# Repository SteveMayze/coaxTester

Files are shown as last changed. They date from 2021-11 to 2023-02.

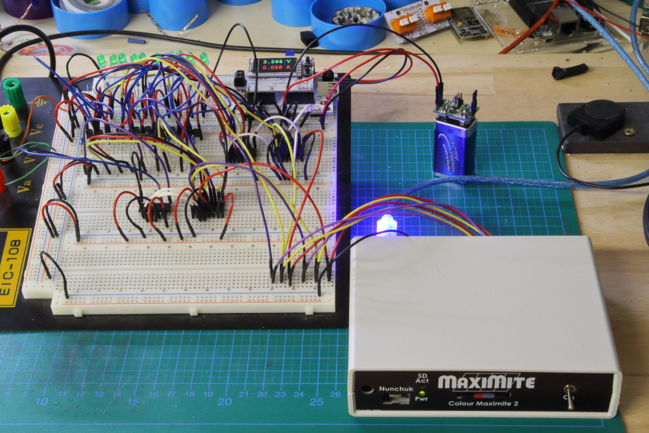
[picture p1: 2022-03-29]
doc/IMG_0029.JPG

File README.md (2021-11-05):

# Coaxial Cable Tester

05 Nov 2021

The purpose of this project is to create a simple device to test a series of coaxial cables where the ends are not situated near each other making it difficult to check continuity. For instance where one end of the cabe is terminated at the multi-switch and the other end at the satillite dish outside. The features of the device should be

1. Able to check continuity of the central conductor and the shielding
2. Able to detect shorts between the central conductor and the shiedling
3. Be able to identify the respective ends of the cable to assist with connection to the LNB and the multi-switch.

The device will be in two parts. A head tester and a tail tester. These devices will work together to determine the above conditions. The head testing will be the main unit and will contain a MCU and a radio unit - or a MCU enabled radio unit. There are a couple of options in this space. The second unit will contain only a MCU enabled radio unit.

# Operation
Each cable will be connected to the head unit and the tail unit respectively as best as it is known. 
```
     ---+
        |            
    L   +---- Low Horiz
    N   |
    B   +---- Low Vert
    1   |
        +--- High Horiz
        |
        +--- High Vert
        |
        +--- DVBT
        |
    L   +---- Low Horiz
    N   |
    B   +---- Low Vert
    2   |
        +--- High Horiz
        |
        +--- High Vert
        |
     ---+
```

The check is then intiated. The head-device will send a signal to the tail-device to open all contacts. Power is then applied to each channel in turn to test if there are any shorts.
The head-device will then send a signal to the tail-device to close all contacts. The head-device will then apply power to each channel again and check for continuity. It is at this stach that the order of the connection can also be verifed. i.e. if the output is sent out to Low Horiz but the return line for High Vert becomes true, then it can be assumed that the coaxial ends are not corrected to the correct port which could result in incorrect connections between the LNB and the multi-switch.

# Components
The list of components are only thoughts as at the time of writing and so not yet fixd. There will need to be a round of proof of concepts to know which will be suitable.

| Component | Description
|---|---|
| MCU | ATMEGA88 |
| Power | 9V Battery - stepped down to 5V and 3.3V |
| Channel Driver | Cascaded 74LS138 3 - 8 pin demultiplexor |
| Radio Modules | XBee running ZigBee |

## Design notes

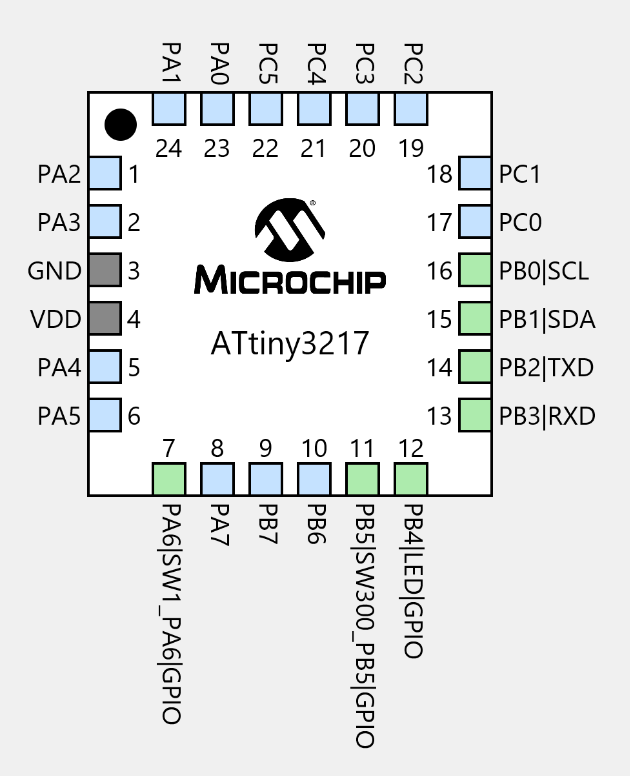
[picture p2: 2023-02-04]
doc/MCC_Pinout.png

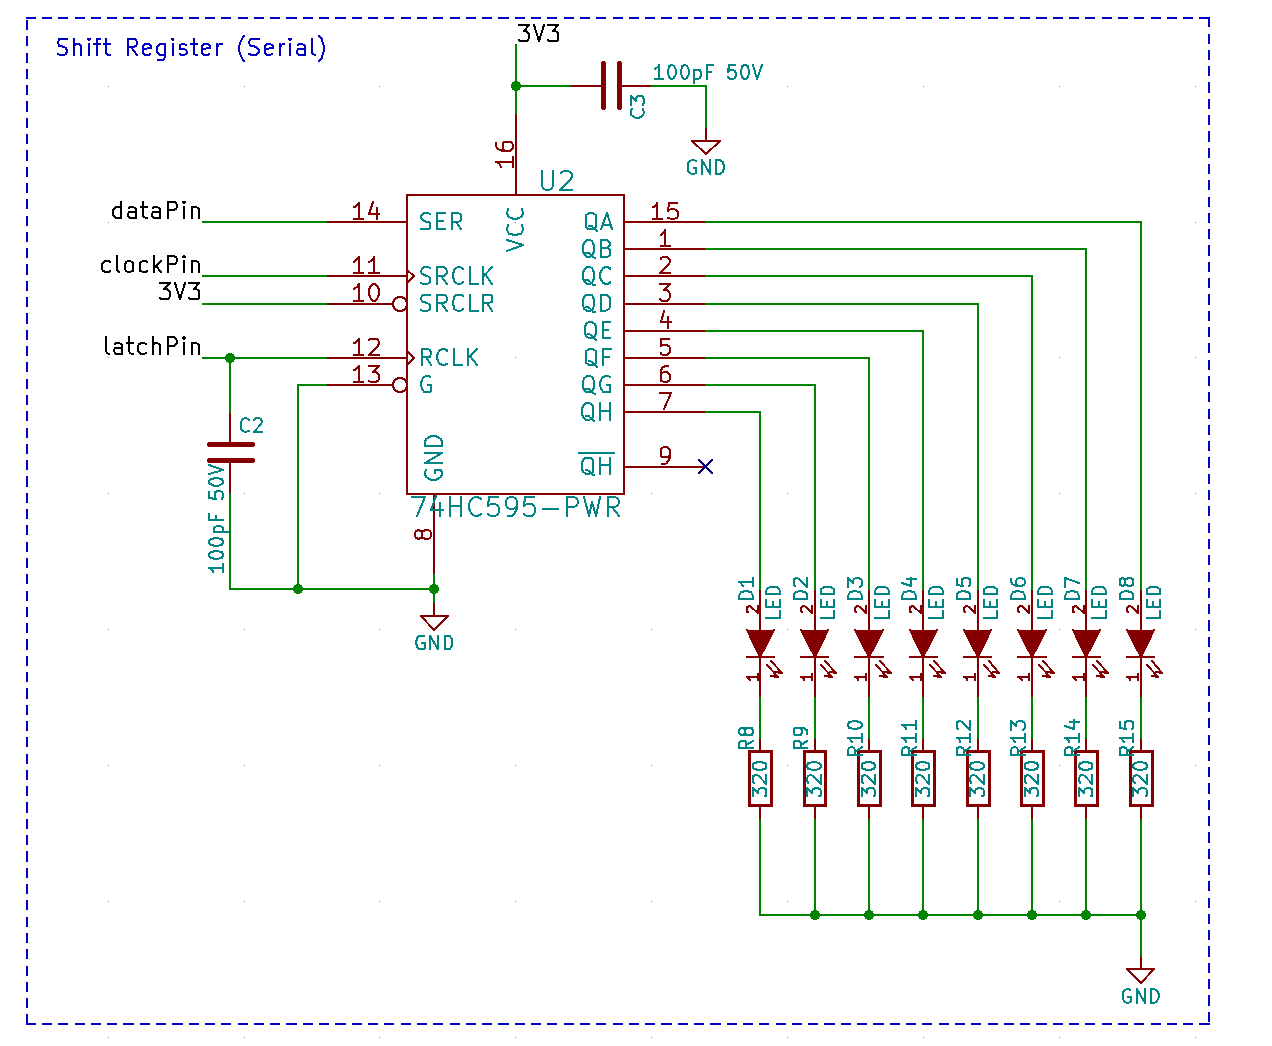
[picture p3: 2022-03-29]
doc/ShiftRegister.png

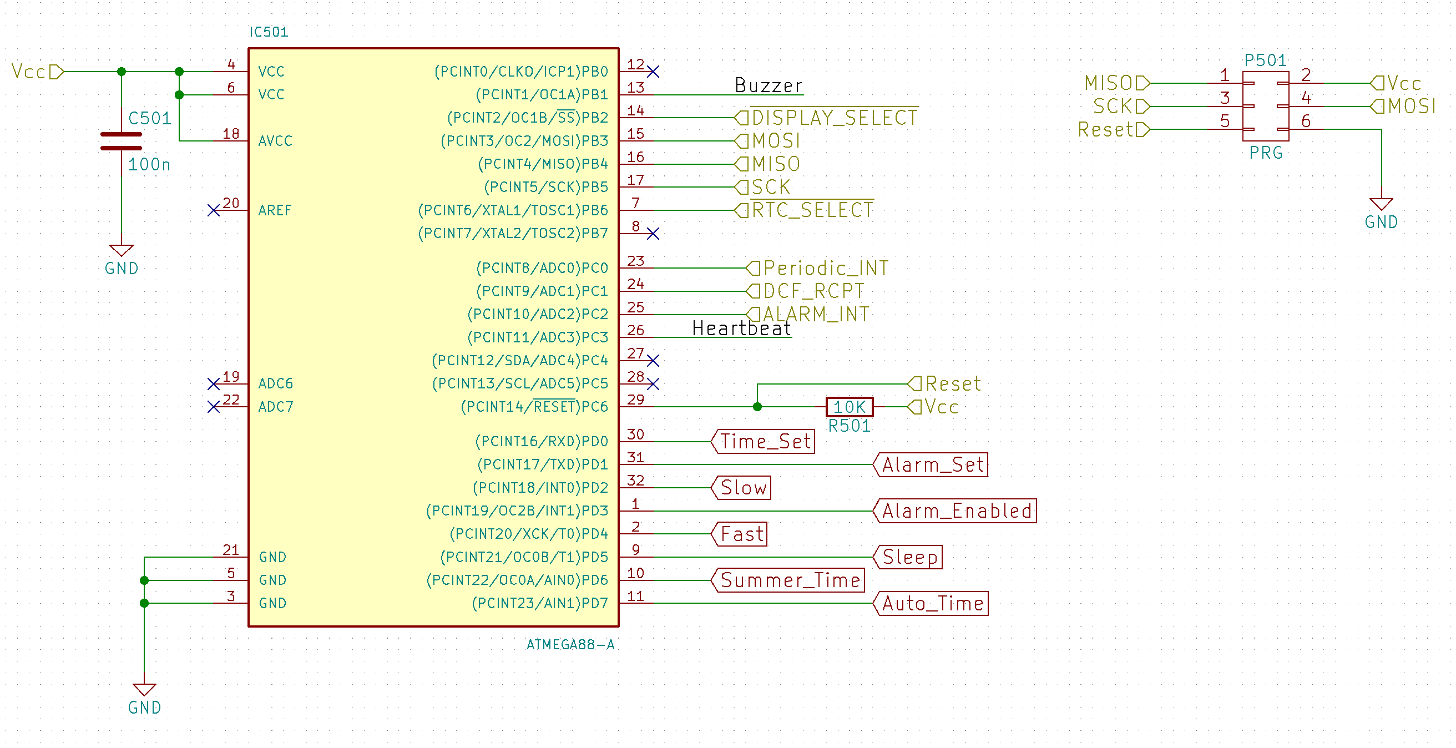
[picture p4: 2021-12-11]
doc/ATMegaConnection.png

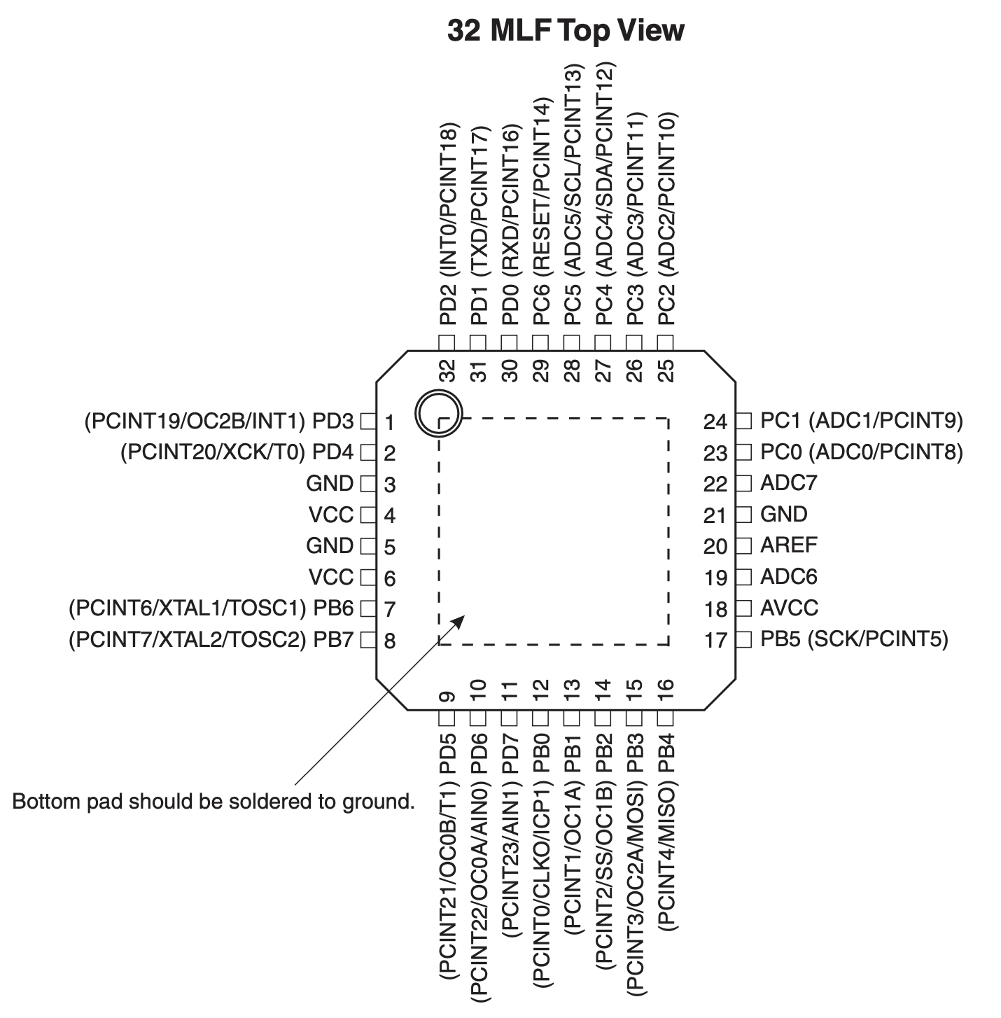
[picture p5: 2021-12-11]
doc/QFN32_ATMega.png

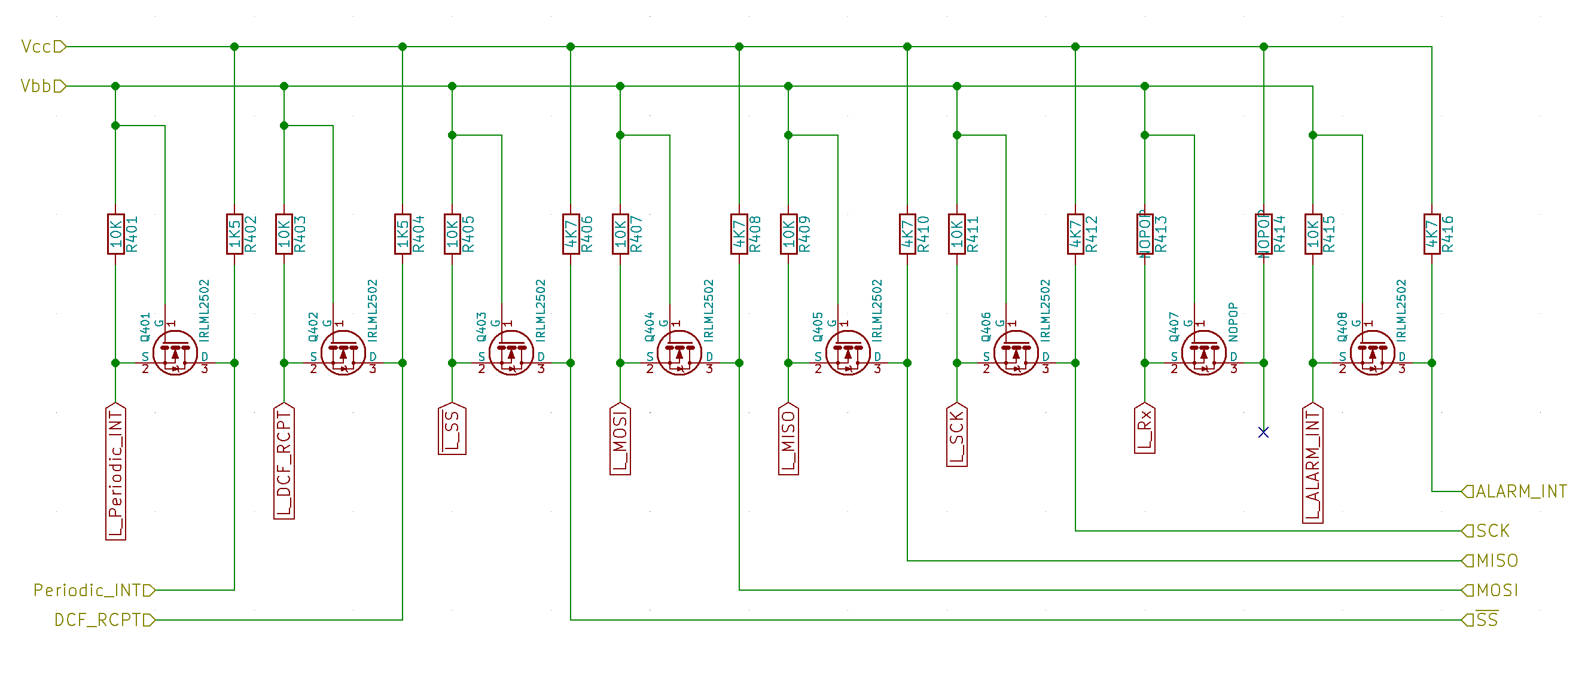
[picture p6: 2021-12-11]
doc/LevelShifter.png

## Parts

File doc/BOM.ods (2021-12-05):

Part | Qty | In Stock | Supplier A | Part | Cost | Supplier B | Part | Cost
ATMega88 | 1 | Y
XBee | 2 | Y
F-Buchse | 18 | Y | Reichelt | FB EPG | 0.5
74LS138 | 2 | Y
CD4532B | 2 | Y | Reichelt | CD4532B - SMD 4532 | 0.38
9V Battery Clip | 2 | Y
LDO 5V 1A | 2 | Y | Digikey | AP1117E50GDITR-ND
LDO 3.3V 0.25A | 2 | Y | Digikey | MCP1700T3302ETTTR-ND

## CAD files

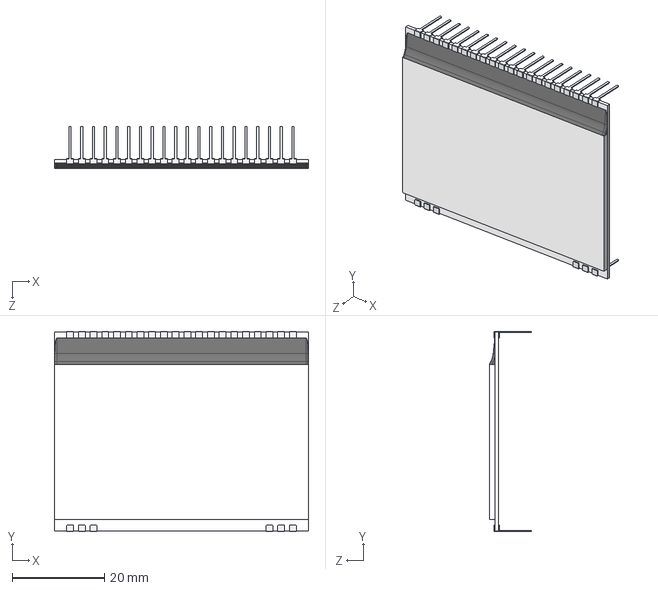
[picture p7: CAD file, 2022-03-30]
freecad/eadogm128/EA DOGM128.STEP
55.0 x 43.4 x 9.20 mm
EA-DOGM128-SCREEN
dogpin x 26

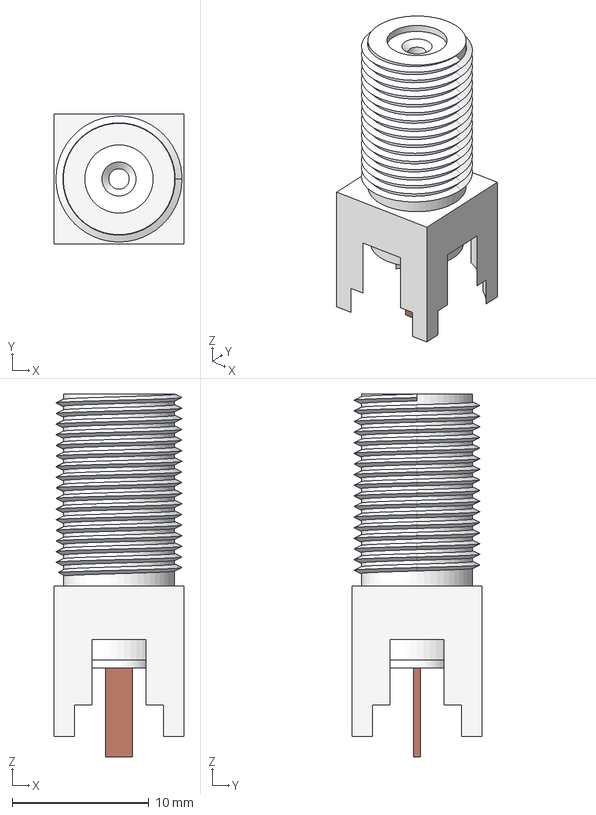
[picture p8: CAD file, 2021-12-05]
freecad/F-Connector_5.step
9.50 x 9.50 x 26.6 mm
Chrome Body
Insulating Tube
Conector Pin

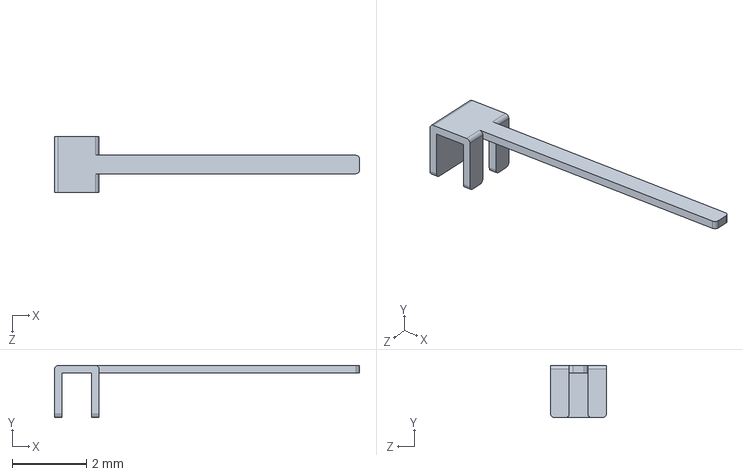
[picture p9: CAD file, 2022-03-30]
freecad/eadogm128/dogpin.SLDPRT
8.20 x 1.40 x 1.50 mm

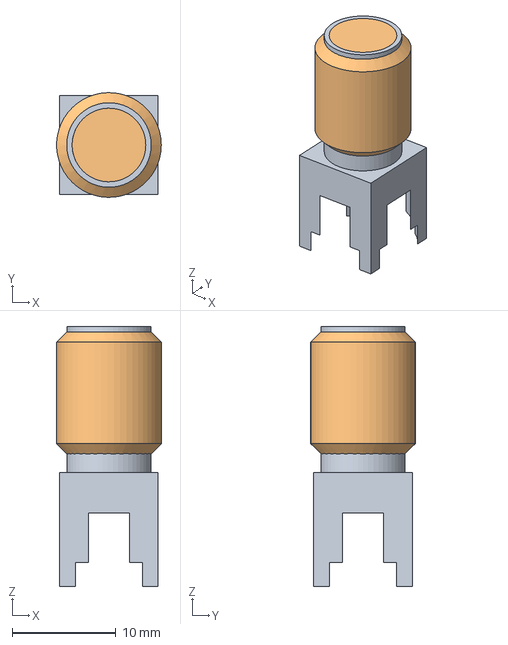
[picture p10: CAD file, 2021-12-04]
freecad/F-Connector_2.FCStd
10.1 x 10.1 x 25.1 mm
M10x12.8-ThreadedRod

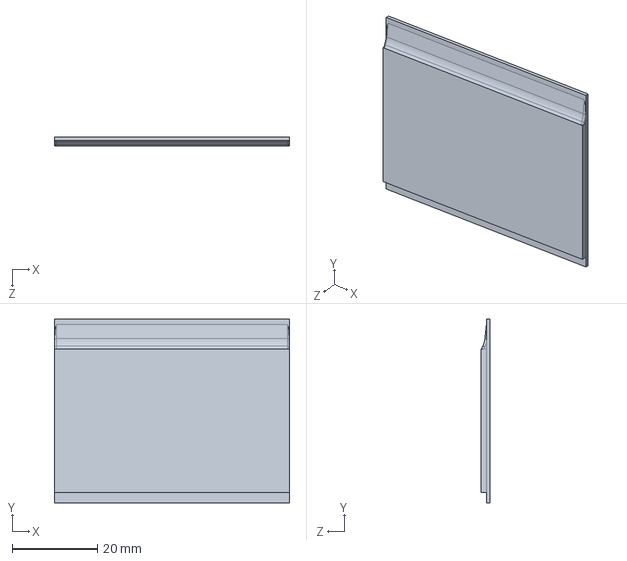
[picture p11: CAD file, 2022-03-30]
freecad/eadogm128/EA-DOGM128-SCREEN.SLDPRT
55.0 x 43.0 x 2.00 mm

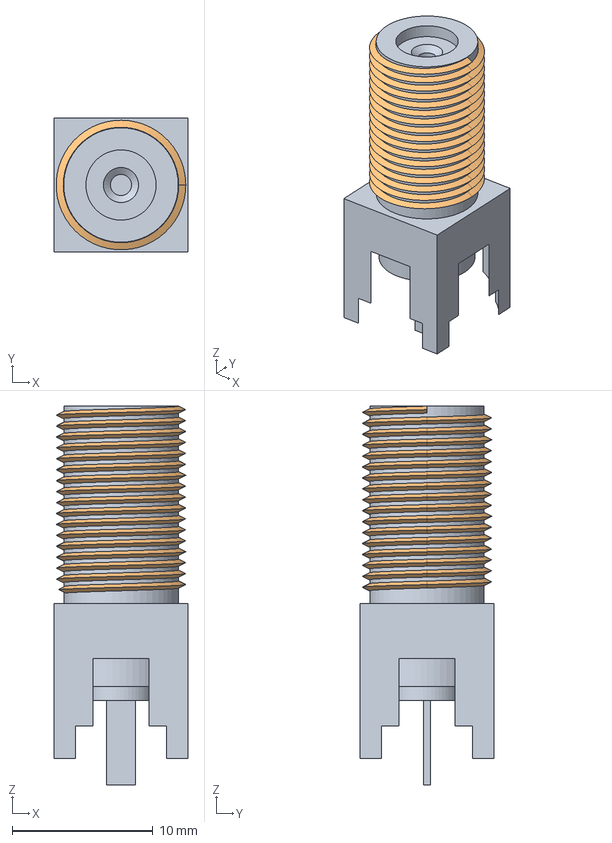
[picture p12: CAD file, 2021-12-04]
freecad/F-Connector_4-BodyHelix.step
9.50 x 9.50 x 27.0 mm

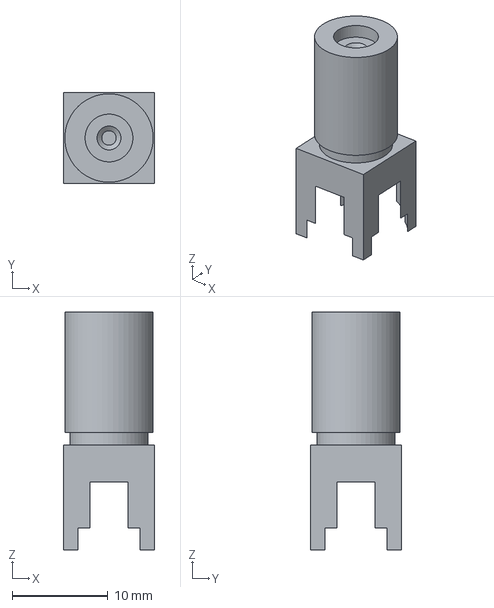
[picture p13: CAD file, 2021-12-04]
freecad/F-Connector.FCStd
9.50 x 9.50 x 24.9 mm

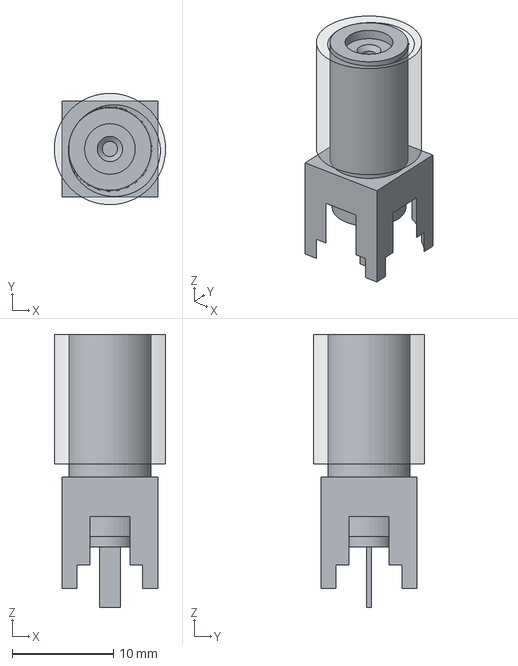
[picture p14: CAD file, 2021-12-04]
freecad/F-Connector_3.step
11.0 x 11.0 x 27.0 mm
M10x12.8-ScrewDie

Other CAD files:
freecad/F-Connector_4.step
freecad/F-Connector_3.FCStd
freecad/F-Connector_4.FCStd
freecad/F-Connector_5.FCStd
freecad/eadogm128/EA DOGM128.SLDASM

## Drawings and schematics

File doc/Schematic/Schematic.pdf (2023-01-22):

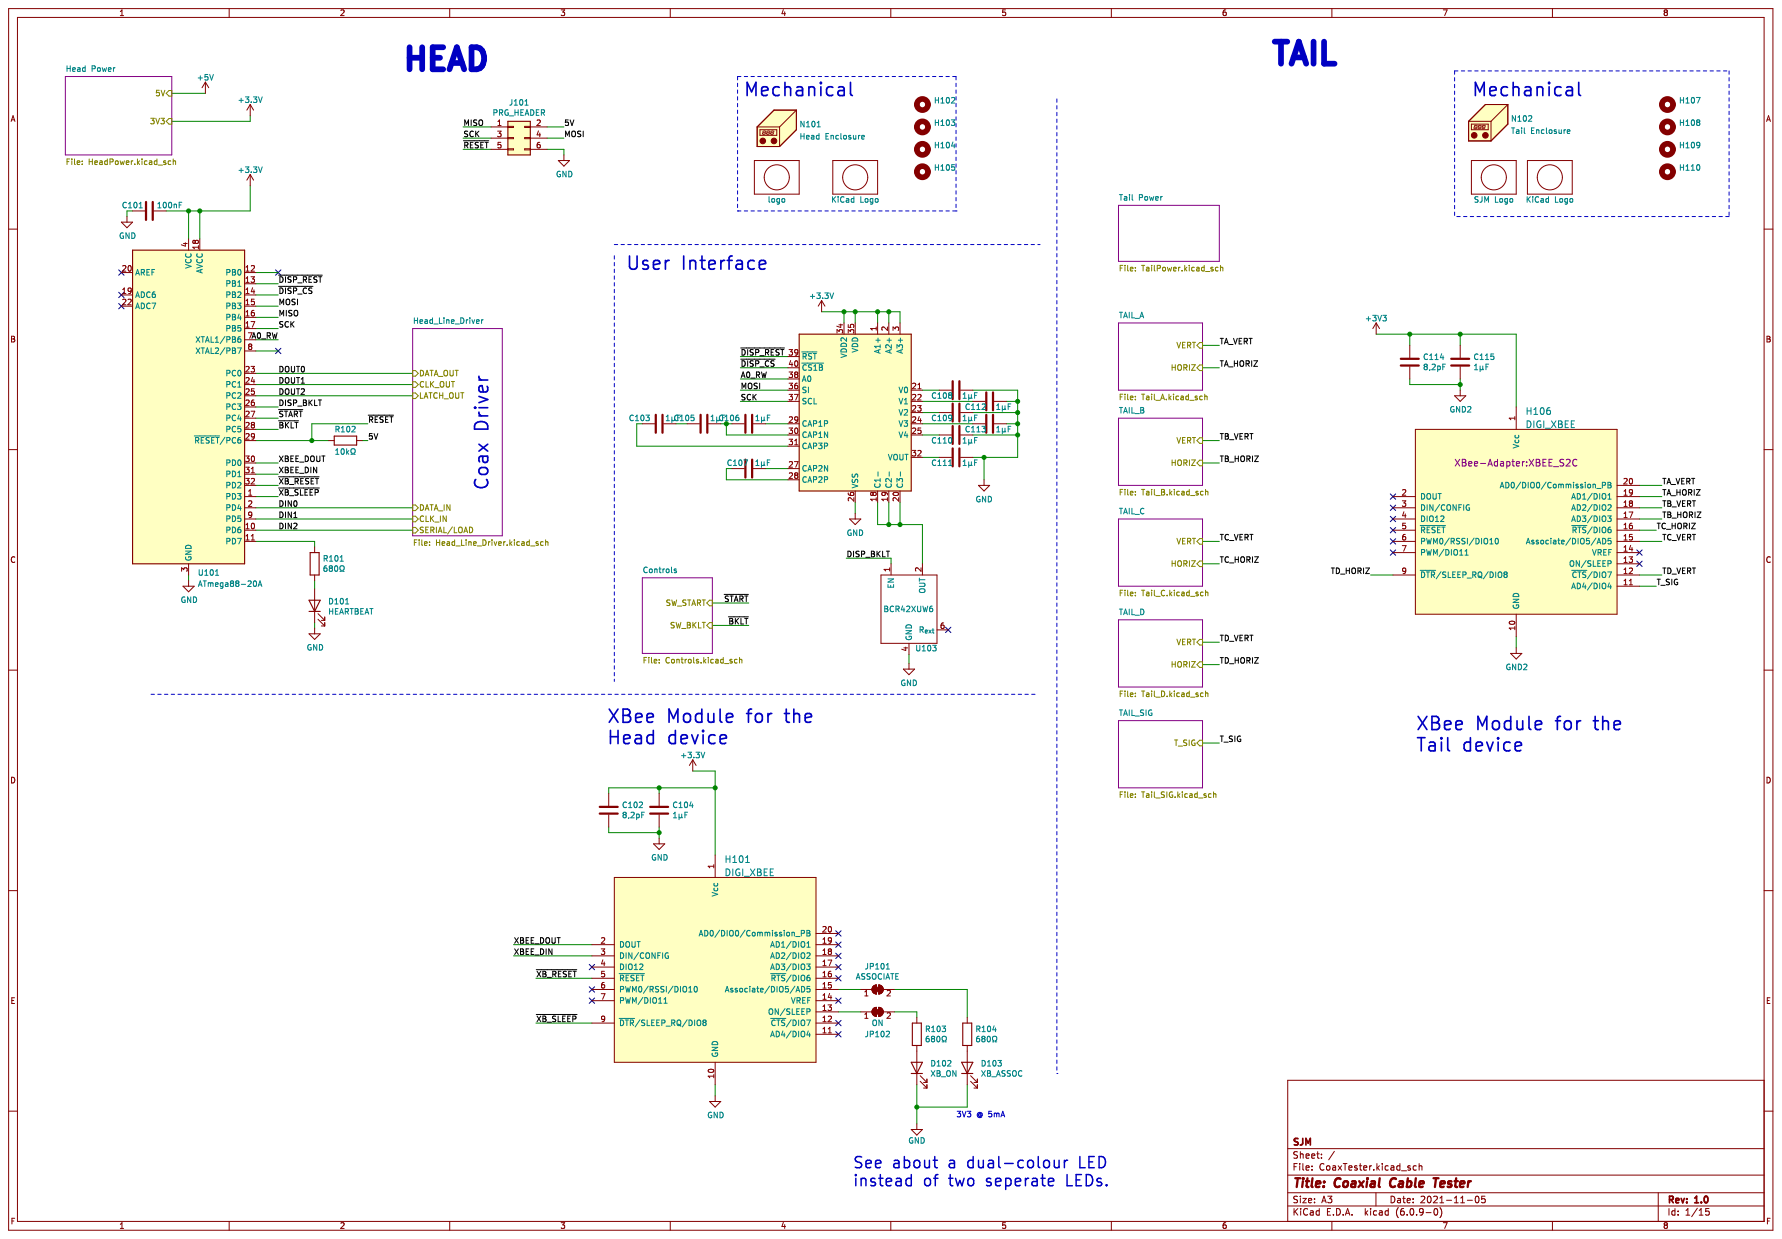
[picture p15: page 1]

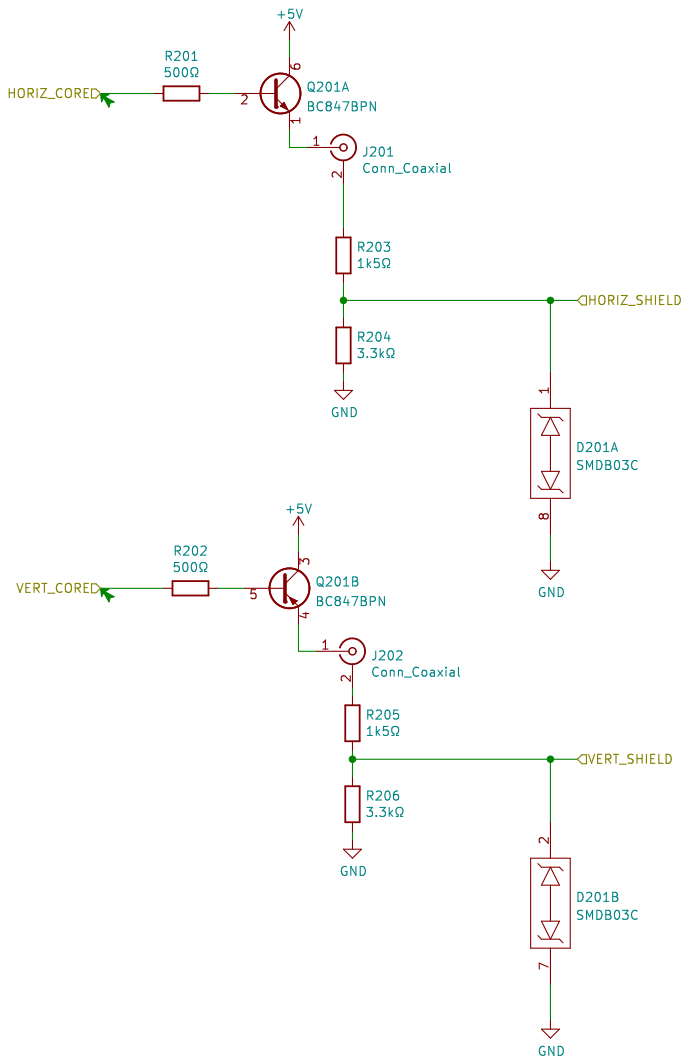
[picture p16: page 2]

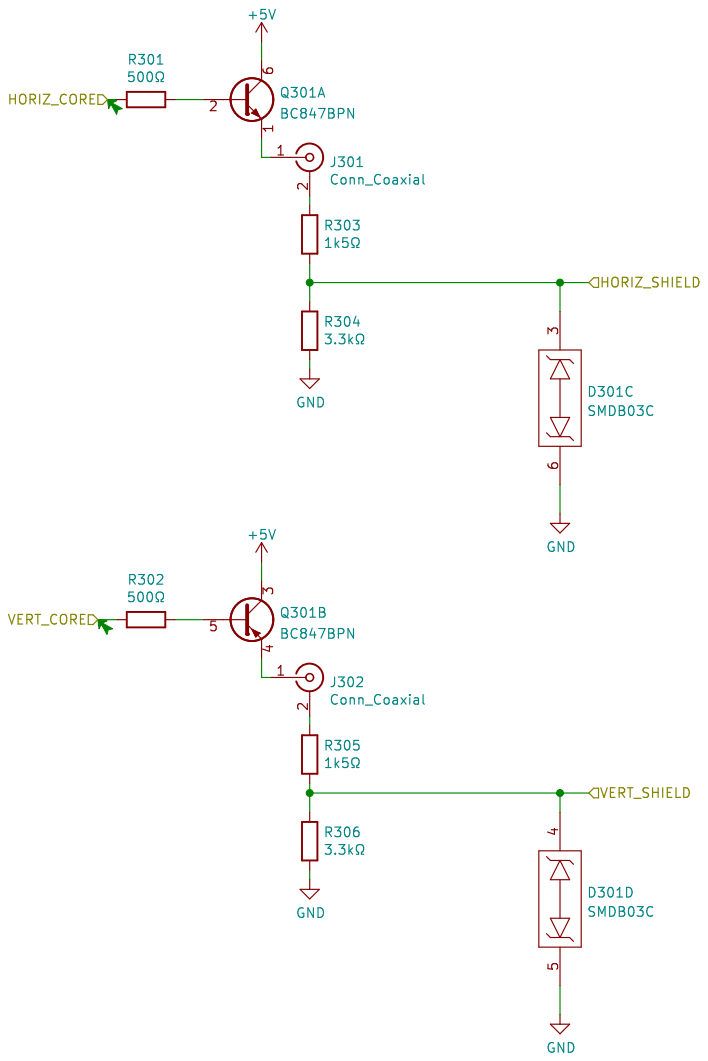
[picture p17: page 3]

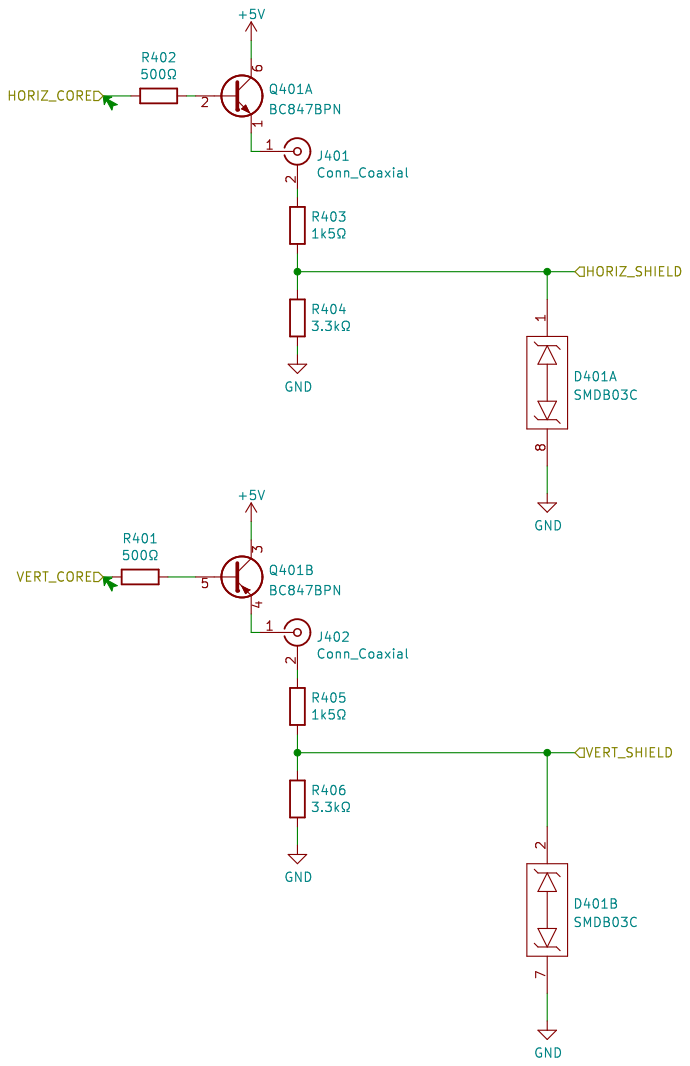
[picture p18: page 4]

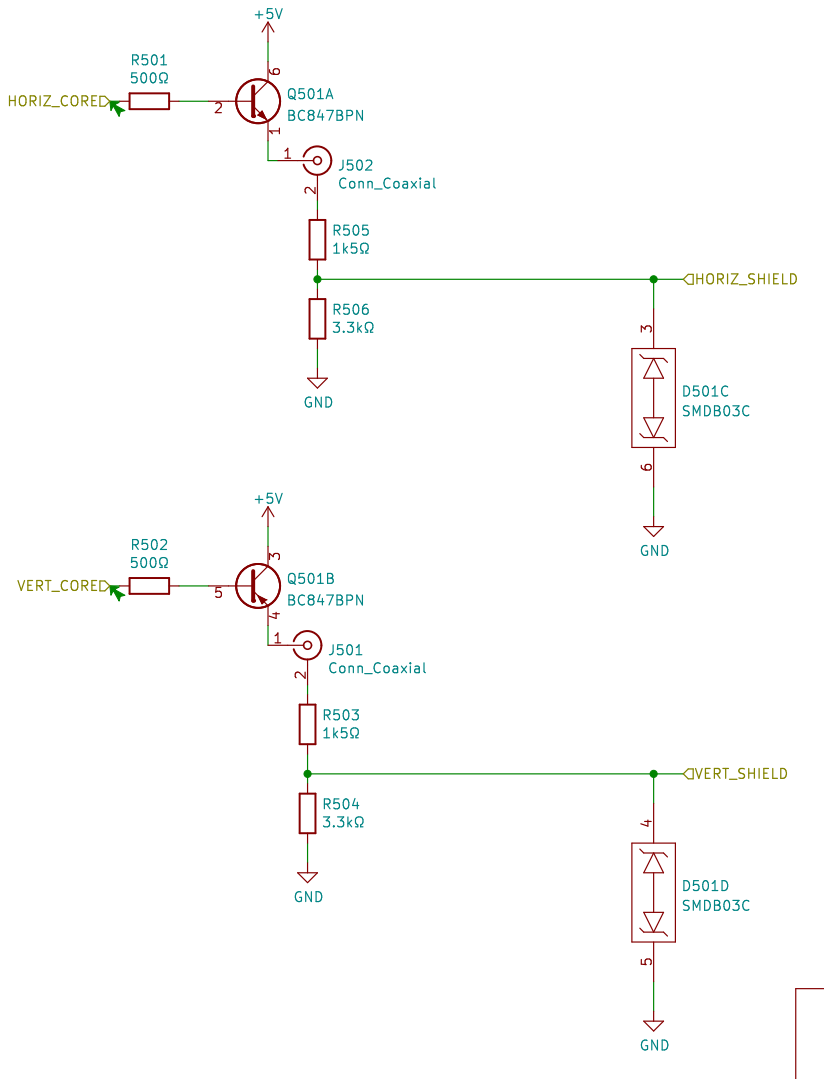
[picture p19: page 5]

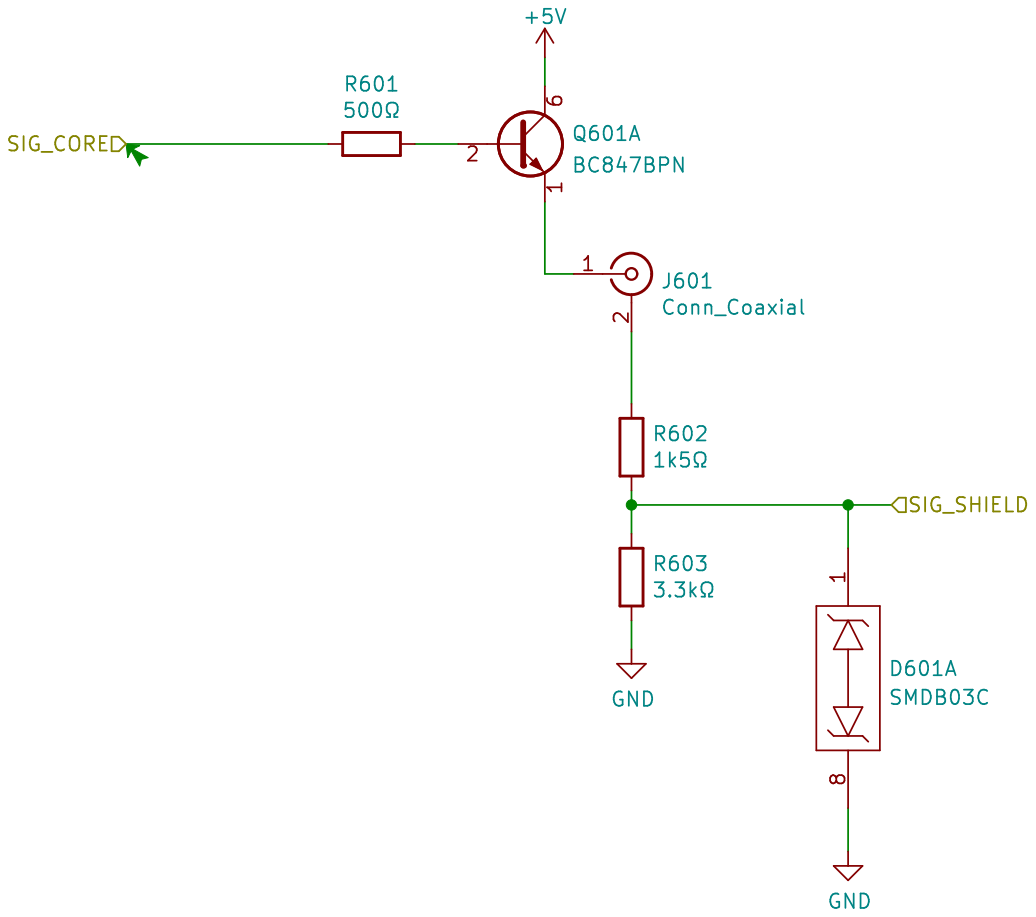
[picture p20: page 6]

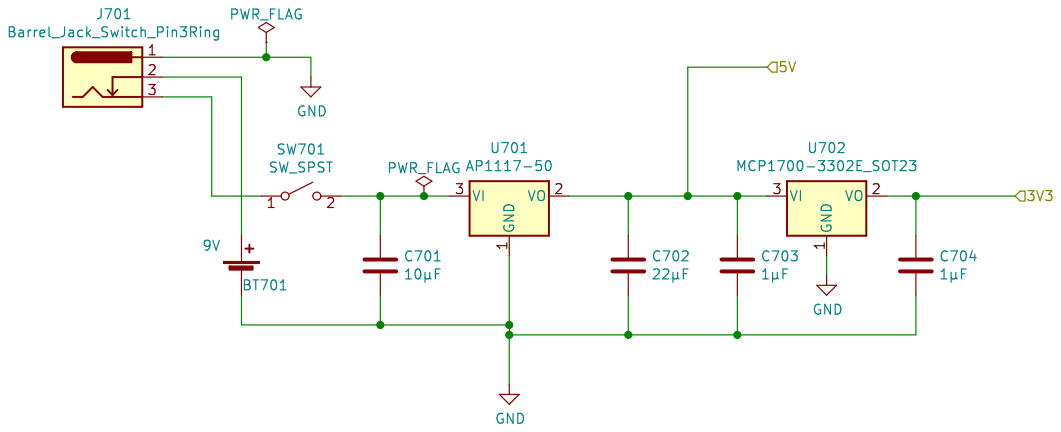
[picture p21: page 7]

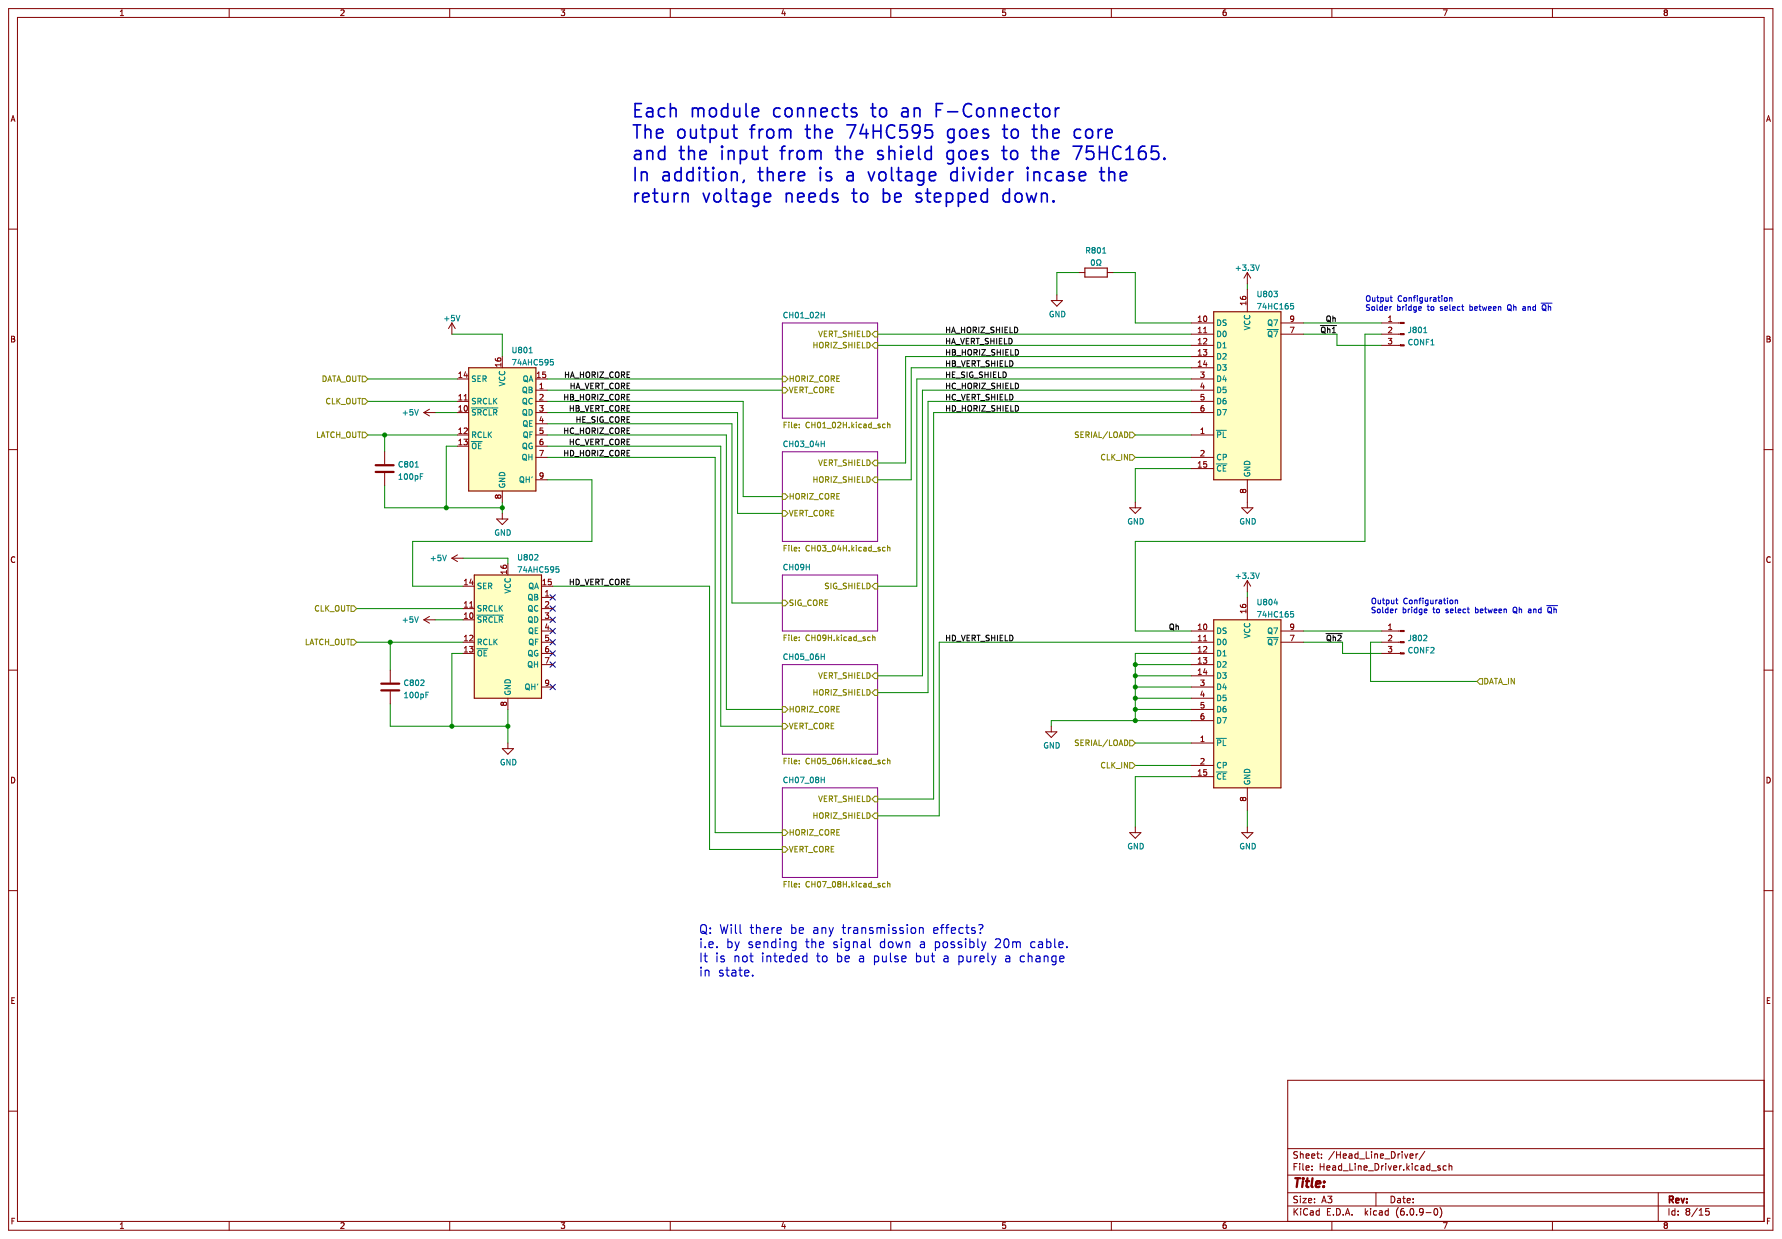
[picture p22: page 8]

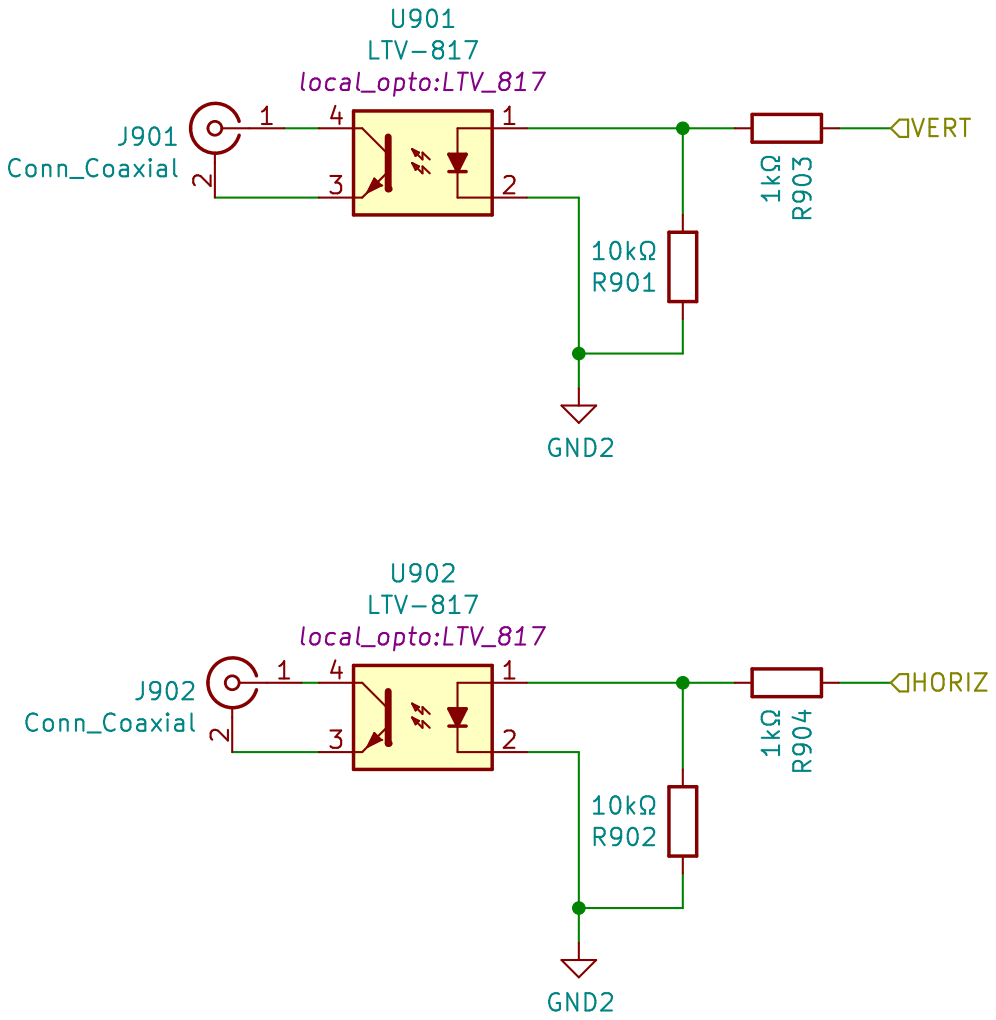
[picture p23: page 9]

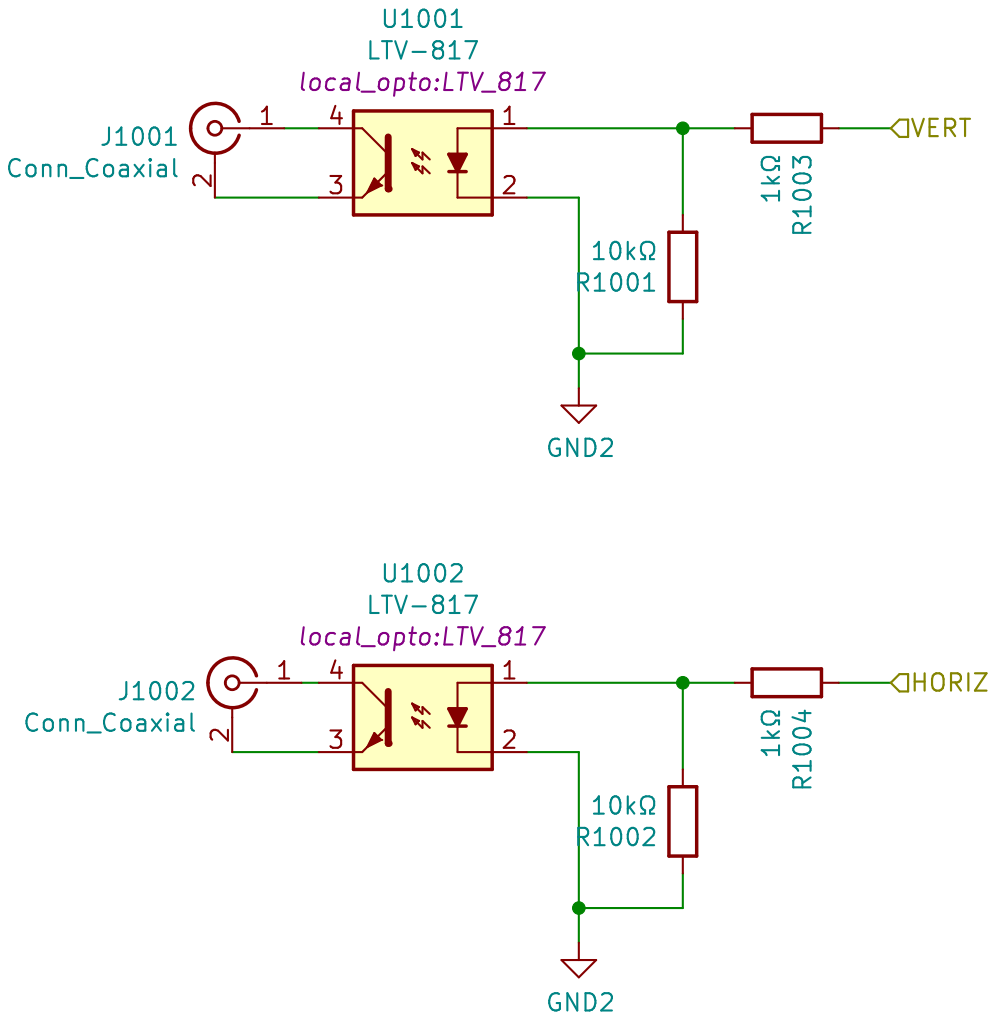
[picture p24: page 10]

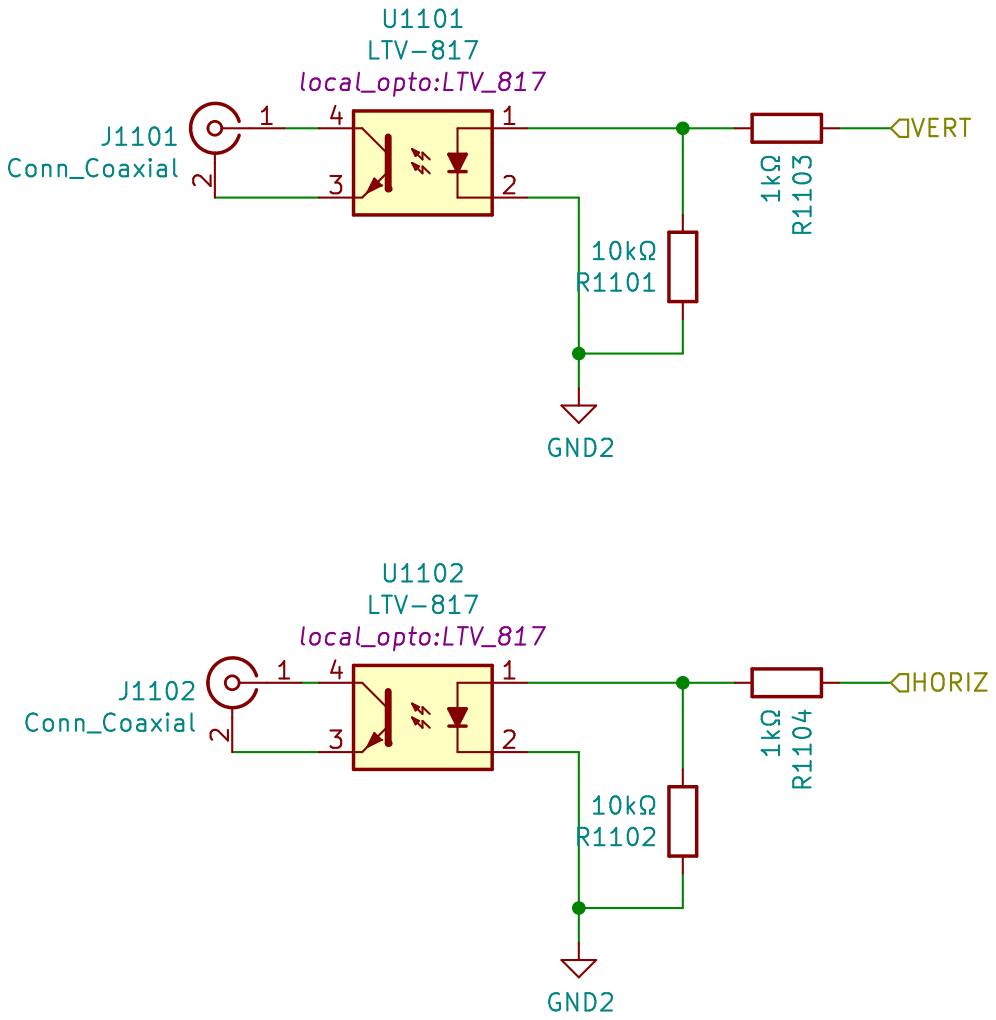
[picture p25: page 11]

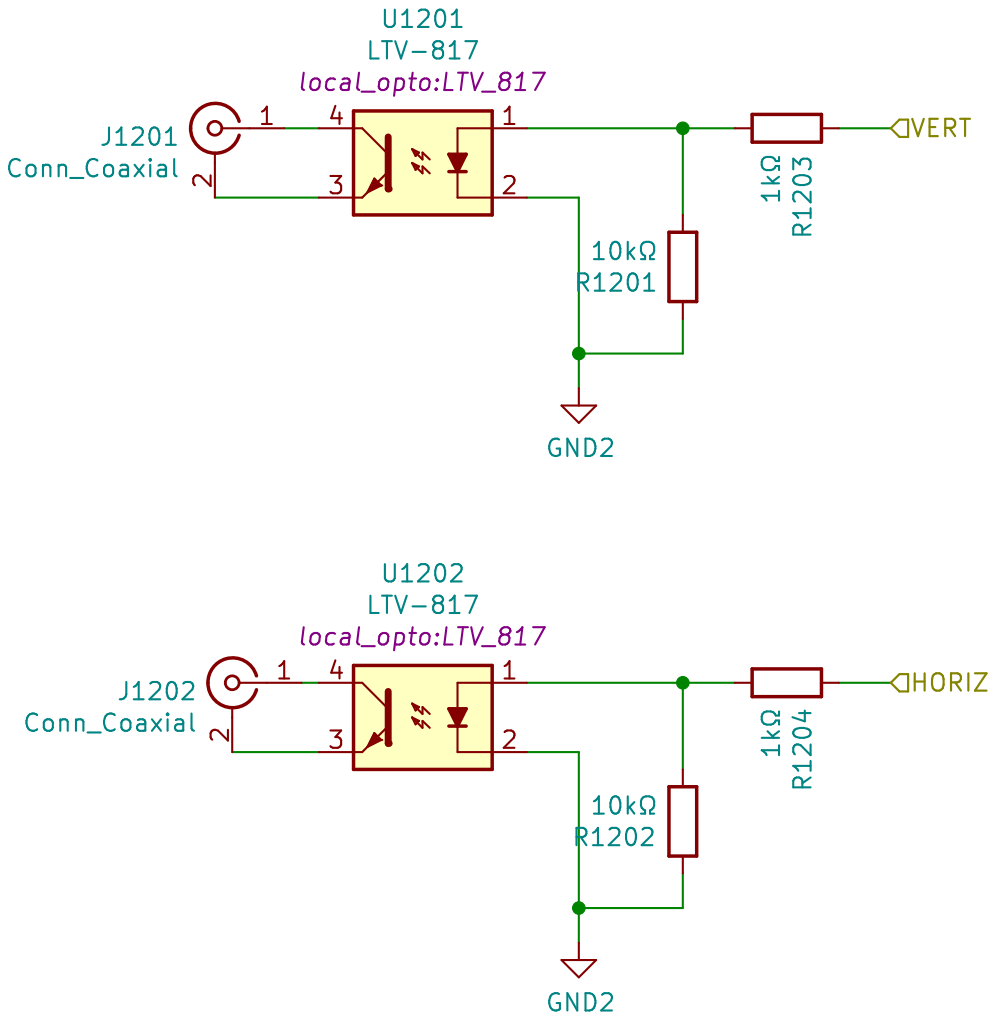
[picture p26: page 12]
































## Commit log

2021-11-05 Initial checking
    [CoaxTester.kicad_pcb, CoaxTester.sch]
2021-12-04 Adds the F-Connector 3d model and updates the kicad model
    [CoaxTester.kicad_pcb, CoaxTester.sch, F-Connector.FCStd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]
2021-12-04 sync some docs
    [BOM.ods]
2021-12-05 Finalise the F-Connector 3D model. Brings documentation into the schematic
    [CoaxTester.sch, F-Connector_5.FCStd, F-Connector_5.step]
2021-12-05 Adds a bit more to the schematic - power module is done
    [BOM.ods, CoaxTester.sch, HeadPower.sch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]
2021-12-11 Adds more to the schematic
    [CH01_02H.sch, CH03_04H.sch, CH05_06H.sch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]
2021-12-12 Adds kicad_lib as a sub module
2021-12-12 Fixed up library reference to a local submodule
    [CoaxTester.sch]
2021-12-12 Completes first cut of the schematic
    [CH01_02H.sch, CH03_04H.sch, CH05_06H.sch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]
2021-12-12 Updates a comment
    [CoaxTester.sch, Head_Line_Driver.sch]
2021-12-12 Neatens the schematic a bit
    [CoaxTester.sch, Head_Line_Driver.sch]
2022-01-06 Updates schematic based on some testing. Adds PDF for review
    [CH01_02H.sch, CH03_04H.sch, CH05_06H.sch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]
2022-01-11 Coax driver done - upgrade to kiCad 6
    [CH01_02H.kicad_sch, CH03_04H.kicad_sch, CH05_06H.kicad_sch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]
2022-01-14 Corrections to the coax driver
    [CH01_02H.kicad_sch, CH03_04H.kicad_sch, CH05_06H.kicad_sch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]
2022-01-14 Updates the schematic PDF
2022-01-19 Introduces shift registers in the coax driver
    [CoaxTester.kicad_sch, Head_Line_Driver.kicad_sch]
2022-01-21 Update the kicad_lib
2022-02-13 Shift register updates - changes the driver from pnp to npn
    [CH01_02H.kicad_sch, CH03_04H.kicad_sch, CH05_06H.kicad_sch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]
2022-03-01 Updates to the shematic for mechanics
    [CoaxTester.kicad_pcb, CoaxTester.kicad_sch, Head_Line_Driver.kicad_sch]
2022-03-01 Proof of concept for XBee tail unit. Correction to XBee symbol
    [CoaxTester.kicad_sch, Head_Line_Driver.kicad_sch]
2022-03-11 Updates to the schematic for XBee
    [CoaxTester.kicad_sch]
2022-03-29 Adds line protection
    [CH01_02H.kicad_sch, CH03_04H.kicad_sch, CH05_06H.kicad_sch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]
2022-03-30 Adds further features to the design
    [CoaxTester.kicad_sch, EA DOGM128.SLDASM, EA DOGM128.STEP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]
2022-06-05 Adds some controls and debounce.
    [CoaxTester.kicad_sch, Controls.kicad_sch, Head_Line_Driver.kicad_sch]
2022-06-05 Adds current control for the display adapter back light
    [CoaxTester.kicad_sch, HeadPower.kicad_sch, TailPower.kicad_sch]
2022-06-06 Updates the schematic and fixes some symbols
    [CH01_02H.kicad_sch, CH03_04H.kicad_sch, CH05_06H.kicad_sch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]
2023-01-22 Schematic complete
    [CH01_02H.kicad_sch, CH03_04H.kicad_sch, CH05_06H.kicad_sch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]
2023-02-06 DRC pass
    [CH01_02H.kicad_sch, CH03_04H.kicad_sch, CH05_06H.kicad_sch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]
2023-03-05 DRC OK
    [CH01_02H.kicad_sch, CH03_04H.kicad_sch, CH05_06H.kicad_sch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]
2023-03-06 Cleaning up and RC checks
    [CH09H.kicad_sch, CoaxTester.kicad_sch, Controls.kicad_sch]
